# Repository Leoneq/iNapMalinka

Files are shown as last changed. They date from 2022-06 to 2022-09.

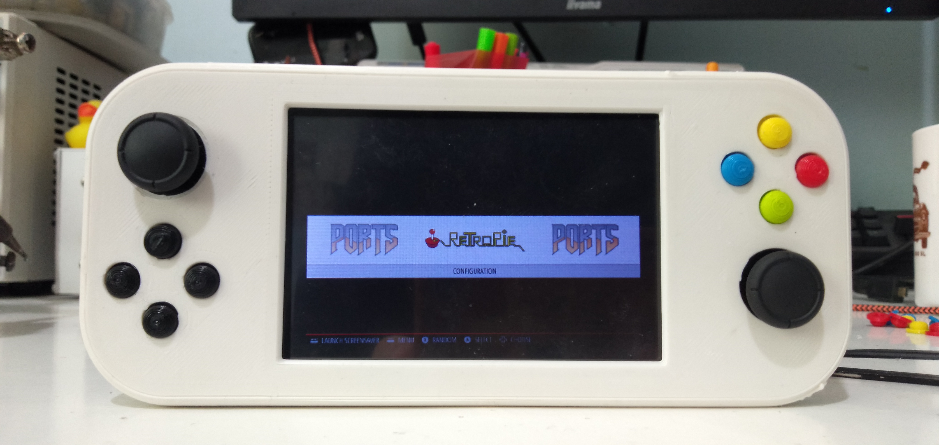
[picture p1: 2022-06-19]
docs/pics/handheld.jpg

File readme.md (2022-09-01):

<div align="center">
  <!--<img src="https://user-images.githubusercontent.com/36605644/186421197-38b28a8d-5e08-4fb6-909e-2cd580bfd80f.png" width=50%>
  <img src="https://user-images.githubusercontent.com/36605644/186671484-4449b216-6cbb-4c44-be21-de949b300e96.jpg" width=50%>-->
  
  <h1>✨ Welcome to the iNap Malinka main page! ✨</h1>
</div>

**iNap Malinka** was mostly made as a decent Raspberry Pi based NRF24L01 transmitter. But as it turns out you can play some games on it as well! It's a small DIY handheld that runs RetroPie so any retro game, including ports, can be played on Malinka. But as it's mostly a device for tinkering on-the-go, there's an additional USB for any kind of peripheral, an HDMI port, and a decent audio section too.
Not only that, it's just as big as your phone, with only 12mm thickness. Two joysticks, 3.5" capacitive touch screen, powered by Raspberry Pi Zero 2W.  
But, if you're interested just about gaming, you can totally ignore the radio section and use it as a small, DIY handheld!
Formally it's a mobile Human-Machine Interface (HMI), as besides the NRF24L01 you can use WiFi and Bluetooth to control your devices!!

## ❤ Why Malinka?
* small and compact size
* big, colorful LCD with touch!
* two joysticks allowing more modern games to be played
* NRF24L01 radio makes it a perfect remote!!
* only 3 external ICs, **without** any aux microcontroller
* stereo sound output and a headphone jack
* custom overlay
* with a keyboard, it can act as a little PC
* uses parts from Nintendo Switch

## 💔 Why NOT?
* if you're a fan of Steam Deck, this device is probably too small for you
* lack of joystick pushbuttons as well as analog triggers
* many tools are needed for assembly
* intermediate soldering skills are needed
* uses parts from Nintendo Switch

## 🚀 Features
* 3.5" 480x320 ILI9488 screen with FT6236 capacitive touch controller
* Raspberry Pi Zero 2W
* 1500mAh lipo battery
* 160x70x12mm (with case)
* two joysticks with 10 bit ADC MCP3008
* PAM8403 amplifier, stereo
* NRF24L01 PA+LNA radio with external antenna (optional)
* Micro-USB for peripherals and USB-C for charging

## 🔨 Kits
There aren't any kits at the moment, you'll need to buy everything by yourself - please visit the [wiki](https://github.com/Leoneq/iNapMalinka/wiki)!
If you want to sell kits of Malinka, please contact me.

## 🎨 Watch it go!
<!--
<div width="60%"> <a href="https://youtu.be/3jcoJ1oJTtw" title="sans gaming"><img src="https://res.cloudinary.com/marcomontalbano/image/upload/v1662052910/video_to_markdown/images/youtube--3jcoJ1oJTtw-c05b58ac6eb4c4700831b2b3070cd403.jpg" alt="sans gaming" /></a></div>
-->
* sans gaming: https://youtu.be/3jcoJ1oJTtw

## ✏ To-do:
* range test video
* doom gaming video
* radio demo video
* improve software a little bit
* and finish wiki ofc

## 😎 Find the project elsewhere
* [OSHWLab](https://oshwlab.com/leoneq/konsola) for schematics and PCB source
* [GitHub](https://github.com/Leoneq/iNapMalinka) for wiki and hardware source
* [Hackaday](https://hackaday.io/project/186233-inap-malinka) for fun
* [Hacksterio](https://www.hackster.io/leonek/inap-malinka-1ea718) for even more fun!!
* [Instructables](https://www.instructables.com/INap-Malinka-Your-NRF24L01-Transmitter-That-Can-Pl/) for the assembly guide
* [Printables](https://www.printables.com/pl/model/265907) for 3D models
* [Thingiverse](https://www.thingiverse.com/thing:5426649) for 3D models but ew

If the project becomes quite popular, I may create a discord server or subreddit dedicated to Malinka!

## 🤝 License
Licensed under CC BY-NC-SA 4.0 - that means you can share, contribute, modify, and remix the source as much as you want!
Please remember to mention the original author and don't change the license. If you want to use it commercially, contact me. 
(there's no guarantee that everything works here, but it should)
Remember that anything you do is at your own risk - the author **is not** responsible for anything you do! Good luck!!  



Because of licensing issues, the code has been moved to [iNapMalinka-code](https://github.com/Leoneq/iNapMalinka-code)!  

## 💖 Sponsor
If you liked this project consider buying me a cup of milk:



I also want to thank [Leo the Leon](https://github.com/leo-the-leon) and [TheTrueShadowFox](https://github.com/TheTrueShadowFox) for the help with this project!!

made with ❤ and 🥛 by  
[@leonek112](https://twitter.com/leoneq112)

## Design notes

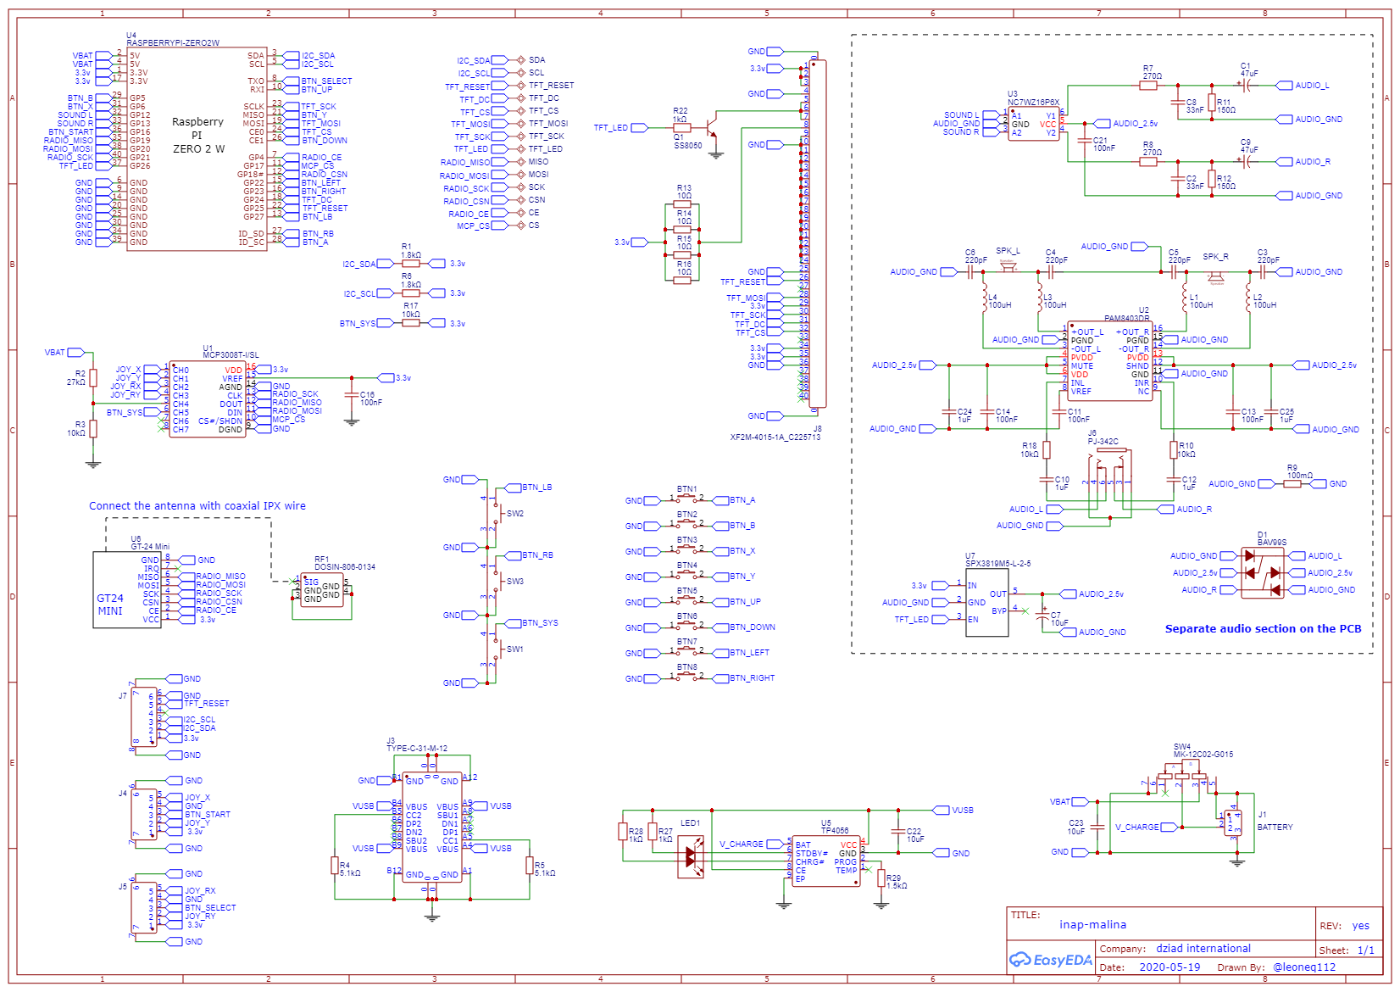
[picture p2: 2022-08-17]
pcb/Schematic_iNap Malinka_2022-08-17.png

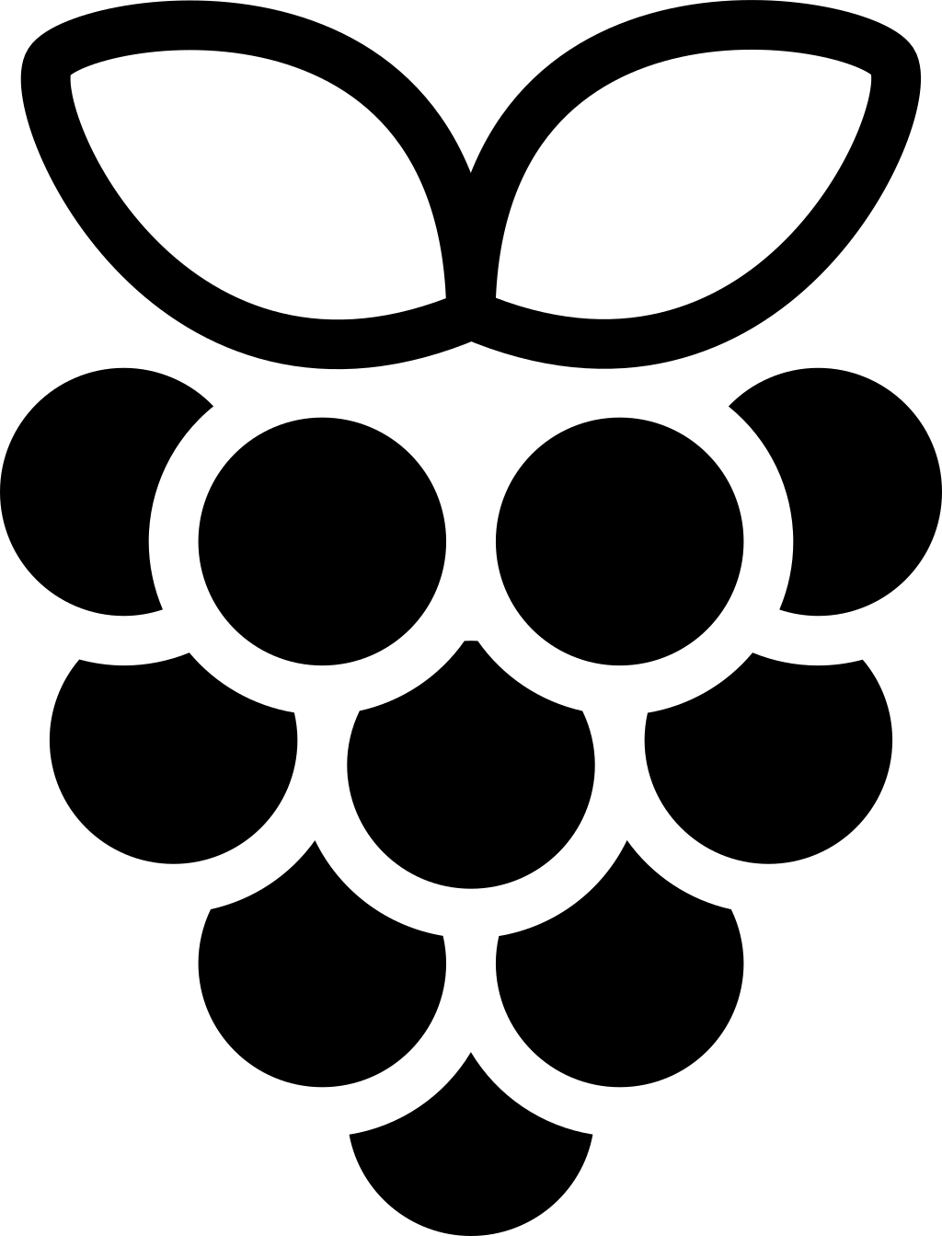
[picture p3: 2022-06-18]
docs/pics/malina.png

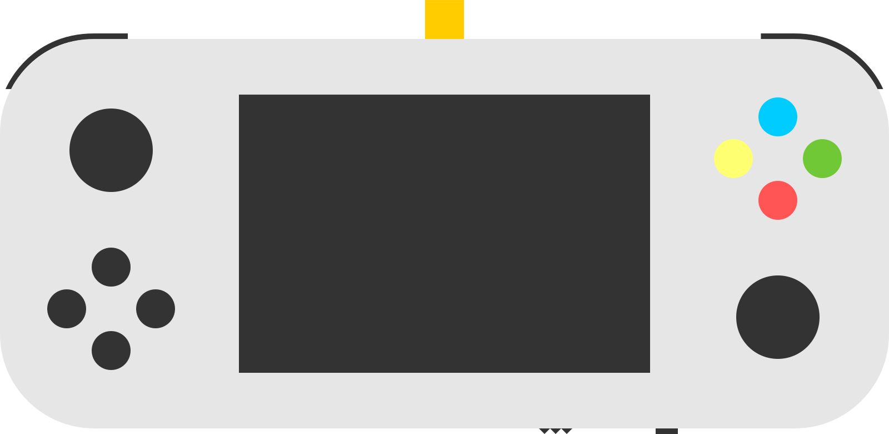
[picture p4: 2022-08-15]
docs/pics/drawing.png

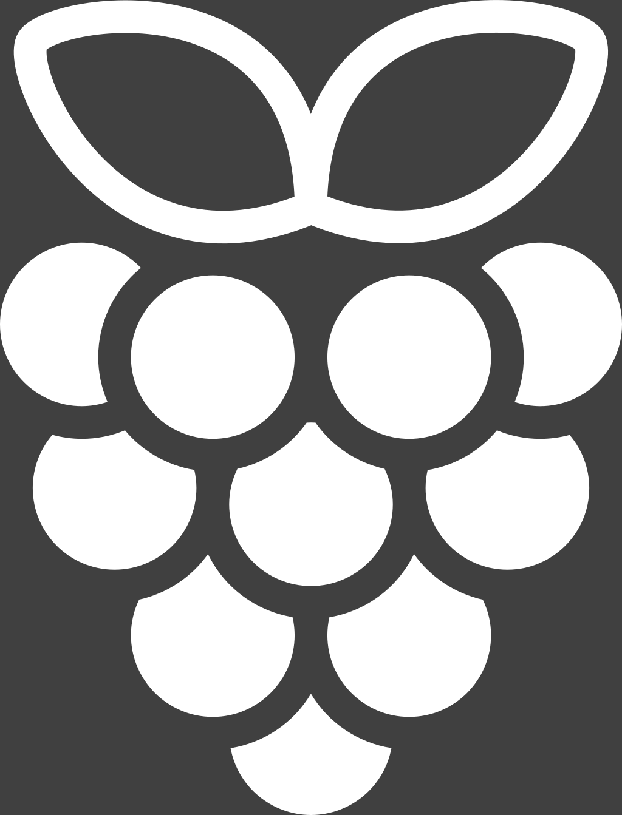
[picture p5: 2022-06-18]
docs/pics/malina_white.png

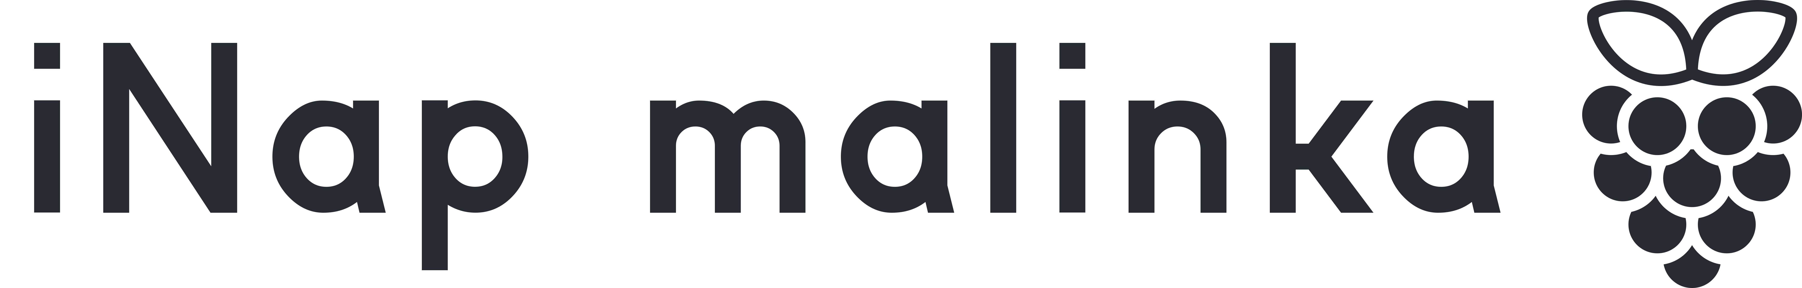
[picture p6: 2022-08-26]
docs/pics/full_malina.png

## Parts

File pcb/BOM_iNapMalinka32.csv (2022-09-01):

ID | Name | Designator | Footprint | Quantity | Manufacturer Part | Manufacturer | Supplier | Supplier Part | Price | Link
1 | K2-3.6×6.1_SMD | BTN1,BTN2,BTN3,BTN4,BTN5,BTN6,BTN7,BTN8 | 4MM BUTTON FIXED | 8 |  |  |  |  |  | none
2 | 47uF | C1,C9 | CAP-TH_BD4.0-P1.50-D0.8-FD | 2 | 47uF 10V 4*5 | ValuePro | LCSC | C43312 | 0.012
3 | 33nF | C2,C8 | C0603 | 2 | CL10B333KB8NFNC | Samsung Electro-Mechanics | LCSC | C307488 | 0.012
4 | 220pF | C3,C4,C5,C6 | C0603 | 4 | CL10B221KB8NNNC | SAMSUNG | LCSC | C1603 | 0.005
5 | 10uF | C7 | CAP-TH_BD4.0-P1.50-D0.8-FD | 1 | 10uF 16V 3*5 | ValuePro | LCSC | C43798 | 0.019
6 | 100nF | C11,C13,C14,C16,C21 | C0603 | 5 | CL10B104KA8NNNC | SAMSUNG | LCSC | C1590 | 0.003
7 | 10uF | C22,C23 | C0805 | 2 | CL21A106KPFNNNE | SAMSUNG | LCSC | C17024 | 0.005
8 | 1uF | C24,C25 | C0603 | 4 | CL10A105KO8NNNC | SAMSUNG | LCSC | C1592 | 0.004
9 | TESTPAD43/80 | CE,CS,CSN,MISO,MOSI,SCK,SCL,SDA,TFT_CS,TFT_DC,TFT_LED,TFT_MOSI,TFT_RESET,TFT_SCK | TESTPAD43/80 | 14 |  |  |  |  |  | none
10 | BAV99S | D1 | SOT-363_L2.1-W1.3-P0.65-LS2.3-BL | 1 | BAV99S | CJ | LCSC | C68987 | 0.047
11 | BATTERY | J1 | CONN-SMD_532610271 | 1 | 532610271 | MOLEX | LCSC | C189700 | 0.107
12 | XF2M-4015-1A_C225713 | J2 | FPC-SMD_40P-P0.50_L4.9-W23.5 | 1 | XF2M-4015-1A | Omron Electronics | LCSC | C225713 | 0.556
13 | TYPE-C-31-M-12 | J3 | USB-C_SMD-TYPE-C-31-M-12 | 1 | TYPE-C-31-M-12 | Rectangular Connectors - Contacts | LCSC | C165948 | 0.249
14 | F0504-H-05-10G-R | J4,J5 | FFC-SMD_5P-P0.50_XFCN_F0504-H-05-10G-R | 2 | F0504-H-05-10G-R | XFCN(台湾兴飞) | LCSC | C2889992 | 0.142
15 | PJ-342C | J6 | AUDIO-SMD_PJ-342C | 1 | PJ-342C | G-Switch(品赞) | LCSC | C2837091 | 0.153
16 | F0504-H-06-10G-R | J7 | FFC-SMD_6P-P0.50_F0504-H-06-10G-R | 1 | F0504-H-06-10G-R | XFCN | LCSC | C510962 | 0.184
17 | 100uH | L1,L2,L3,L4 | L0805 | 4 | MLF2012C101KT000 | TDK | LCSC | C68035 | 0.044
18 | 19-223/R6GHC-A01/2T(YY) | LED1 | LED-ARRAY-SMD_4P-L1.6-W1.5-TR | 1 | 19-223/R6GHC-A01/2T(YY) | Everlight Elec | LCSC | C182213 | 0.086
19 | SS8050 | Q1 | SOT-23-3_L2.9-W1.3-P1.90-LS2.4-BR | 1 | SS8050 | CJ | LCSC | C2150 | 0.016
20 | 1.8kΩ | R1,R6 | R0603 | 2 | ERJ3EKF1801V | PANASONIC | LCSC | C278609 | 0.01
21 | 27kΩ | R2 | R0603 | 1 | RS-03K2702FT | Guangdong Fenghua Advanced Tech | LCSC | C304727 | 0.001
22 | 10kΩ | R3,R17 | R0603 | 4 | 0603WAF1002T5E | UniOhm | LCSC | C25804 | 0.001
23 | 5.1kΩ | R4,R5 | R0603 | 2 | 0603WAF5101T5E | UniOhm | LCSC | C23186 | 0.001
24 | 270Ω | R7,R8 | R0603 | 2 | ERJ3GEYJ271V | PANASONIC | LCSC | C403465 | 0.007
25 | 100mΩ | R9 | R1206 | 1 | 1206W4F100LT5E | UniOhm | LCSC | C25334 | 0.009
26 | 150Ω | R11,R12 | R0603 | 2 | ERJ3RBD1500V | PANASONIC | LCSC | C336847 | 0.021
27 | 10Ω | R13,R14,R15,R16 | R0603 | 4 | 0603WAF100JT5E | UniOhm | LCSC | C22859 | 0.001
28 | 1kΩ | R22,R27,R28 | R0603 | 3 | ERJP03J102V | PANASONIC | LCSC | C427272 | 0.051
29 | 1.5kΩ | R29 | R0603 | 1 | ERJ-3EKF1501V | PANASONIC | LCSC | C193392 | 0.009
30 | DOSIN-806-0134 | RF1 | SMA-SMD_DOSIN-806-0134 | 1 | DOSIN-806-0134 | dosinconn(德索五金) | LCSC | C709670 | 0.98
31 | -SPEAKER | SPK_L,SPK_R | FILTER-SMD_1206-2P-L3.2-W1.6-L | 2 | GSPK1003PN-8R0.2W-L100 | INGHAi | LCSC | C530534 | 0.613
32 | 1TS003B-1400-3500A | SW1,SW2,SW3 | KEY-SMD_1TS003B | 3 | 1TS003B-1400-3500A | HYP | LCSC | C319392 | 0.04
33 | MK-12C02-G015 | SW4 | SW-SMD_G-SWITCH_MK-12C02-G015 | 1 | MK-12C02-G015 | G-Switch(品赞) | LCSC | C2911519 | 0.114
34 | MCP3008T-I/SL | U1 | SOIC-16_L9.9-W3.9-P1.27-LS6.0-BL | 1 | MCP3008T-I/SL | MICROCHIP(美国微芯) | LCSC | C2651321 | 5.146
35 | PAM8403DR | U2 | SOIC-16_L9.9-W3.9-P1.27-LS6.0-BL | 1 | PAM8403DR | DIODES | LCSC | C17337 | 0.425 | Available on green audio amplifier boards.
36 | NC7WZ16P6X | U3 | SC-70-6_L2.2-W1.3-P0.65-LS2.1-BR | 1 | NC7WZ16P6X | ON Semicon | LCSC | C114148 | 0.772
37 | RASPBERRYPI-ZERO2W | U4 | RPI2W_USB | 1 |  |  |  |  | 15
38 | TP4056 | U5 | SOP-8_L4.9-W3.9-P1.27-LS6.0-TL-EP-1 | 1 | TP4056X | TOPPOWER(南京拓微) | LCSC | C2763448 | 0.205
39 | GT-24 Mini | U6 | GT24 MINI | 1 |  |  |  |  | 1.83
40 | SPX3819M5-L-2-5 | U7 | SOT-23-5_L3.0-W1.7-P0.95-LS2.8-TL | 1 | SPX3819M5-L-2-5 | EXAR | LCSC | C21454 | 0.77
41 | M2x3x3 brass insert |  | M2x3x3 | 6 |  |  |  |  |  | https://aliexpress.com/item/1005002529889373.html
42 | M2x10 |  | M2x10 | 6 | KM2X10 | Shuntian | LCSC | C357345 | 0.0018
43 | M1.4x4 |  | M1.4x10 | 4 | KA1.4X4 | Shuntian | LCSC | C357505 | 0.0009
44 | Nintendo Switch Lite buttons pads |  | left and right | 1 |  | Nintendo |  |  | 1.53 | https://aliexpress.com/item/1005003071063706.html
45 | Nintendo Switch Joystick |  |  | 2 |  | Nintendo |  |  | 2.27 | https://aliexpress.com/item/4001209760173.html
46 | 3.5inch IlI9488 screen with CTP |  |  | 1 | LHC03540 | LiangHaoCai |  |  | 14.85 | https://aliexpress.com/item/4001248271603.html
47 | 1500mAh 3.7v LiPo 40x50x5mm |  |  |  | 504050 | Liter Energy |  |  | 5.18 | https://aliexpress.com/item/4000036287535.html

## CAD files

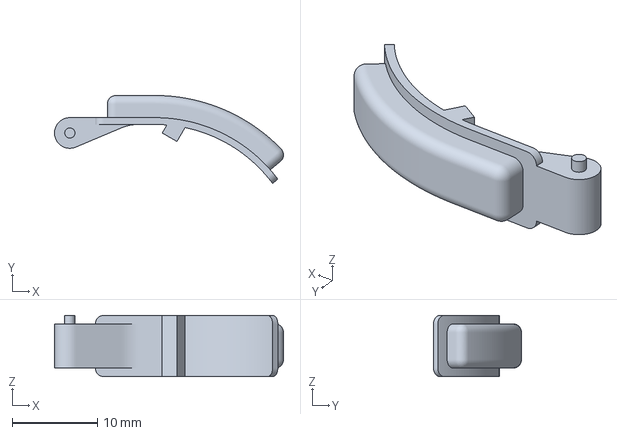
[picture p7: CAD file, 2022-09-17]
print/trigger_right.3mf
26.9 x 10.3 x 7.20 mm

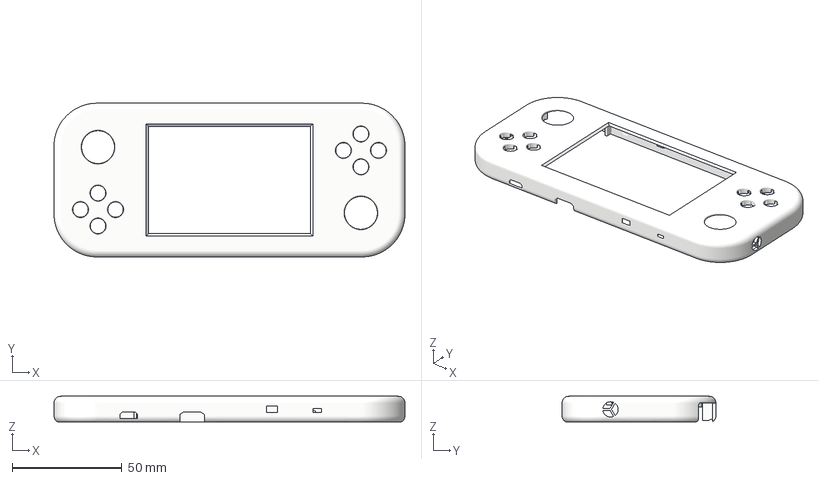
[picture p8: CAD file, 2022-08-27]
print/shell_no_sma.3mf
160.2 x 70.2 x 11.7 mm

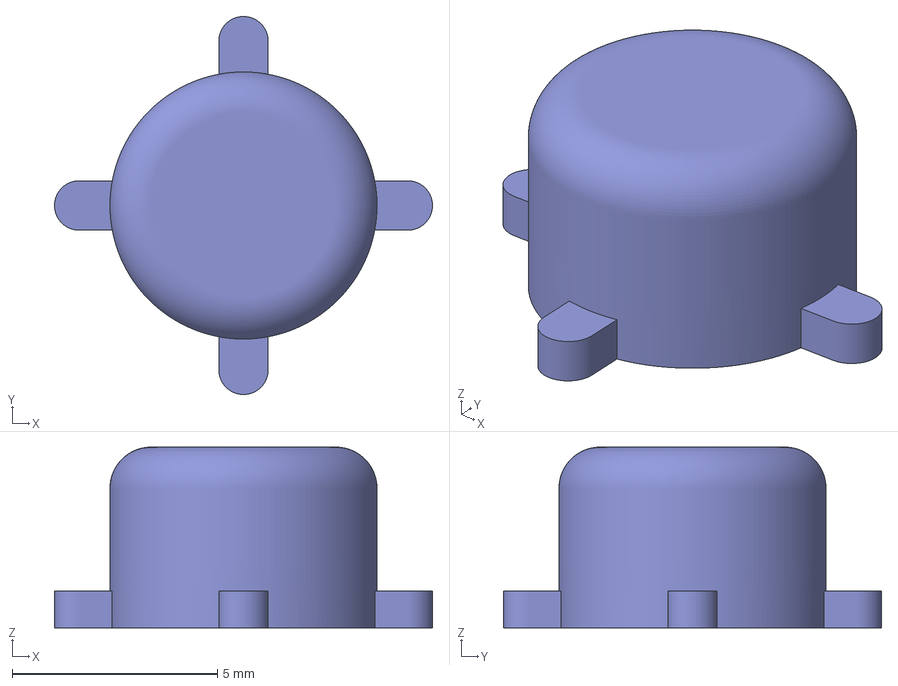
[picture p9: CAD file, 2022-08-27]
print/btn.3mf
9.20 x 9.20 x 4.40 mm

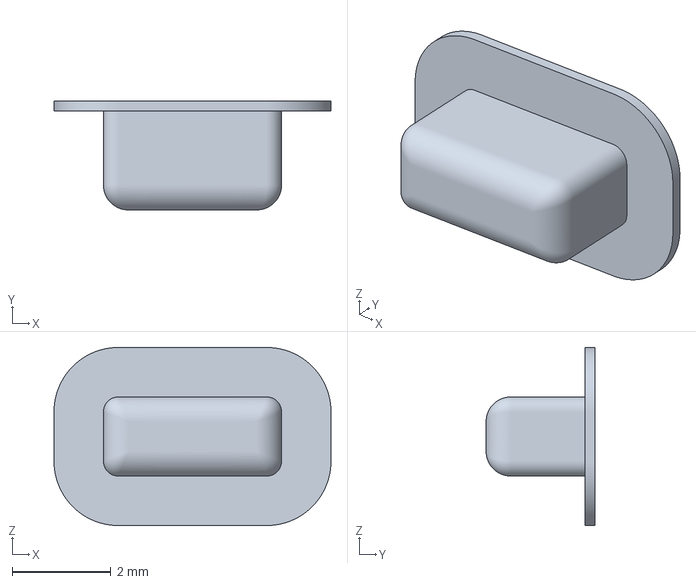
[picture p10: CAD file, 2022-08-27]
print/sysbtn.3mf
5.60 x 2.20 x 3.60 mm

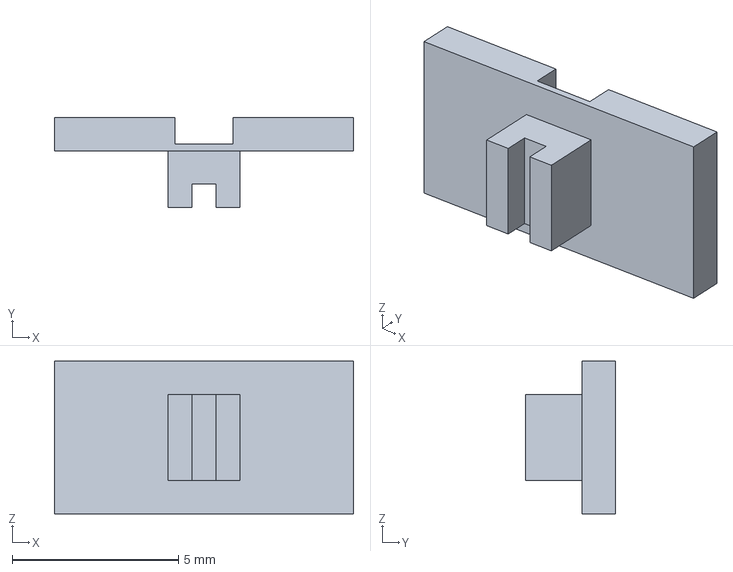
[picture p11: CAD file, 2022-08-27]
print/switch.3mf
9.00 x 2.70 x 4.60 mm

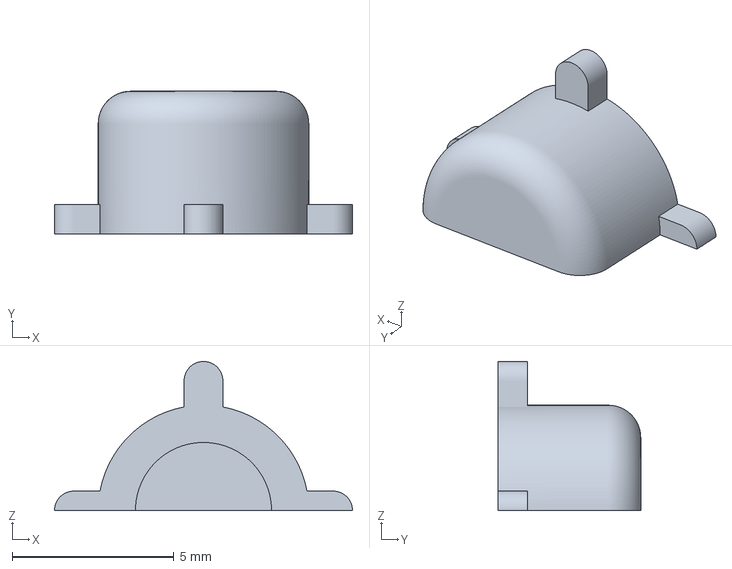
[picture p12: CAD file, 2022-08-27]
print/btn_half.3mf
9.20 x 4.40 x 4.60 mm

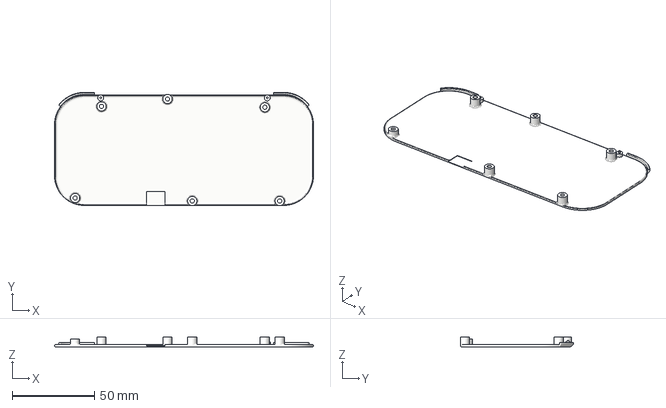
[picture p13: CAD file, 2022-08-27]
print/cover.3mf
157.0 x 68.6 x 6.20 mm

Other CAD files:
print/trigger_left.3mf
print/shell.3mf
print/malinka.f3z

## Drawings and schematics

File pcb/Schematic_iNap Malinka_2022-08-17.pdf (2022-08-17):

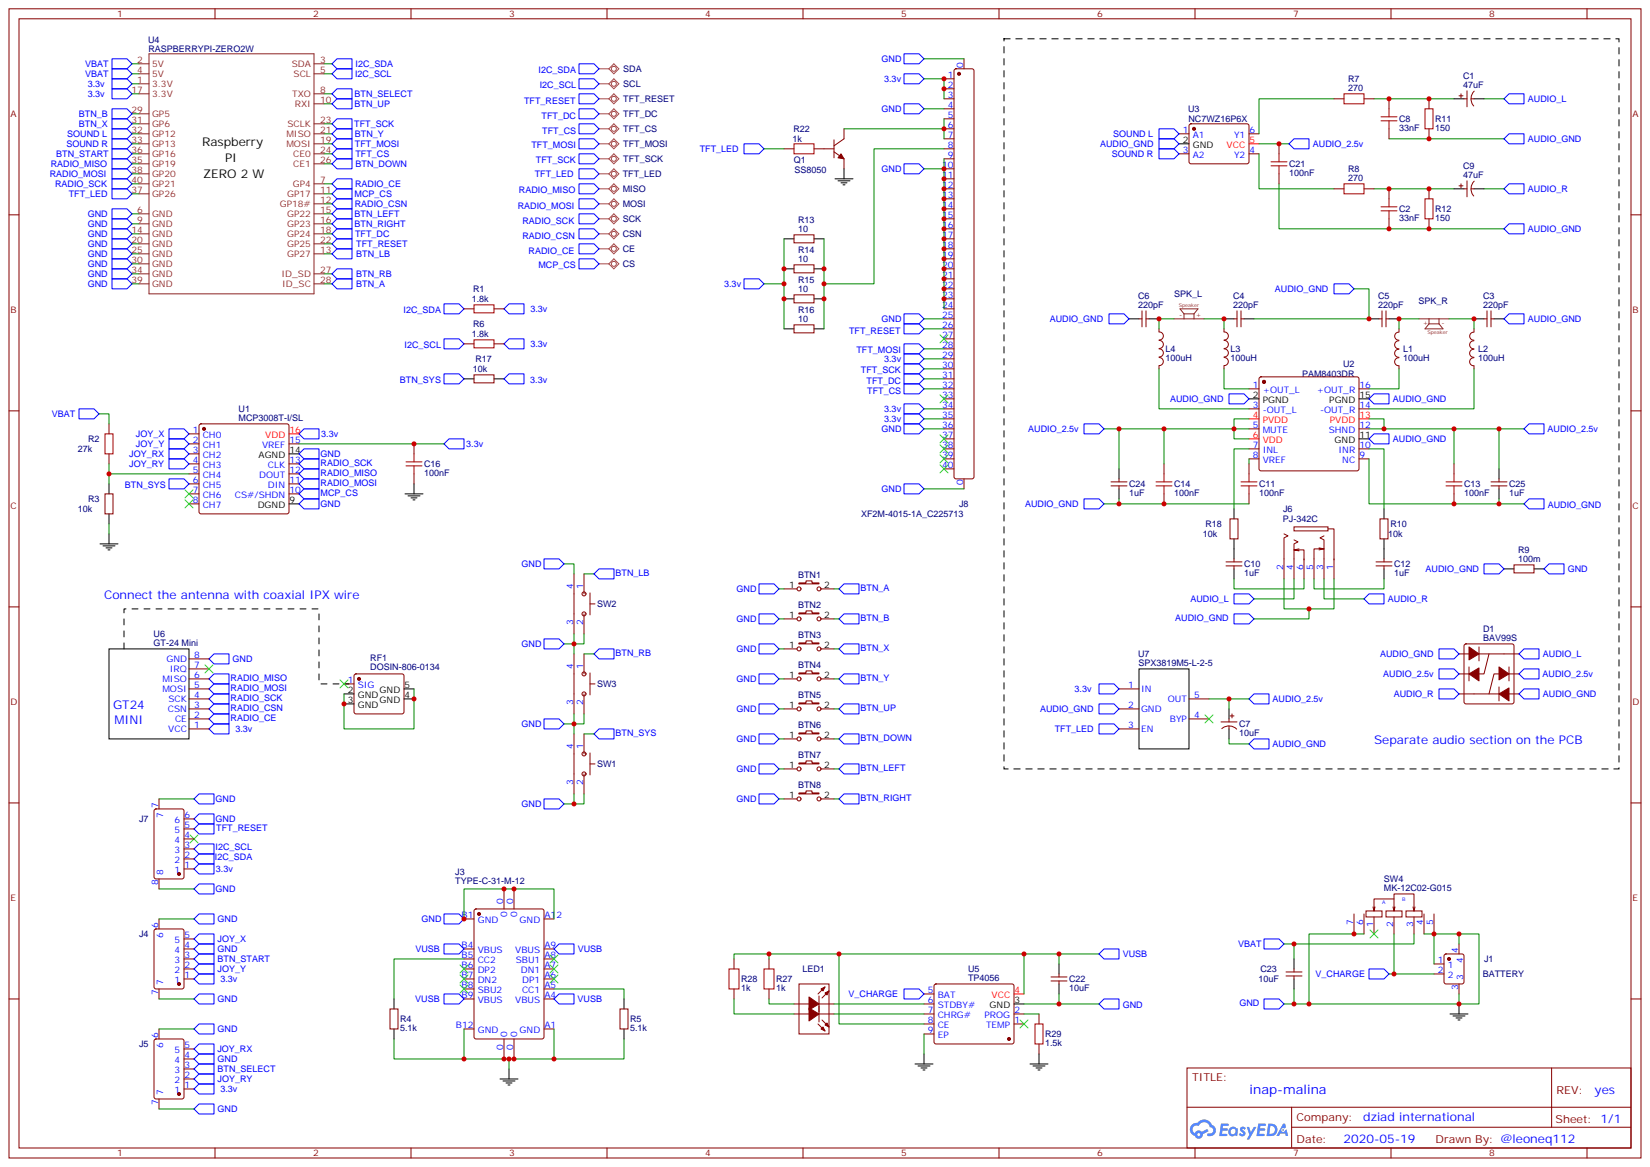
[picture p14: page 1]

MCP3008T-I/SL
CS#/SHDN 10 DIN 11 DOUT 12 CLK 13 AGND 14 VREF 15 VDD 16

Connect the antenna with coaxial IPX wire

Separate audio section on the PCB

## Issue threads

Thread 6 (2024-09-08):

Cant find the material list!

Pocke01, 2024-09-08:
Like the title says. I can only find some parts under features but I would like to have all the parts. Could you please add a material list. :)

Leoneq, 2024-09-09:
Hi! The part list is included as a BOM file in the 'pcb' folder: [BOM_iNapMalinka32.csv](https://github.com/Leoneq/iNapMalinka/blob/main/pcb/BOM_iNapMalinka32.csv)

Pocke01, 2024-09-09:
Thank you!  How could i miss that one.

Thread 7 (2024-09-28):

question

Pocke01, 2024-09-28:
Hi,

Have a question.  The pcb i got when order from the files in the repo has r10, c12,c18, c10 but the picture of your finished board does not have those.  Is it only to ignore them ? They are on the sides of C11

And the place where you say "DO NOT solder L1-L4, or C3-C6, but instead short them as shown:"
c3-c6 is left as is? no solder at all?

Leoneq, 2024-09-29:
Hi!
Yes, the pictured board is a prototype version, good eye. I was creating instructions along when soldering the prototype, and the sound turned out to be of poor quality till those passives were added.
You need to solder them as the schematic shows, I will update the wiki soon.

As for L1-L4 and C3-C6 I agree it's a wrong sentence, I'll change that too - but as shown, short L1-L4 unless you still get a poor quality sound, and C3-C6 should be left free (just as the picture shows)

Pocke01, 2024-09-29:
What passives goes on  r10, c12,c18, c10 ?

And is it possible to run without battery only usb-c power?  Cause we havent recieved the battery yet. But my son has finished almost all the soldering.

Leoneq, 2024-09-29:
As seen here: https://github.com/Leoneq/iNapMalinka/blob/main/pcb/Schematic_iNap%20Malinka_2022-08-17.pdf
In the audio section you can see what values those are. To run without battery you will need to short the `VBAT` with `VUSB`; follow the schematic to see what would be the best place to put the jumper on. Everything should work fine except the overlay, which may show something like "200%" battery charge.

Pocke01, 2024-09-29:
Thanks for the help!

Closed 2024-09-29.

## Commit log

2022-06-18 added some cool files
    [config.txt]
2022-06-19 added some essential files
    [BOM_iNap Malinka_2022-06-16.csv, button.3mf, buttons_connected.3mf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]
2022-07-06 Updated 3D models
    [btn_side.3mf, button.3mf, buttons_connected.3mf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]
2022-07-06 More changes
    [BOM_iNap Malinka_2022-06-16.csv, BOM_iNapMalinka32.csv]
2022-08-19 updated bom
    [BOM_iNapMalinka32.csv, OLD_BOM_iNapMalinka32.csv]
2022-08-27 updated models
    [btn.3mf, btn_half.3mf, cover.3mf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]
2022-08-27 added f3z file
    [malinka.f3z, shell_no_sma.3mf]
2022-09-01 correct invalide quote (#5)
    made the file directly editable on github
    [BOM_iNapMalinka32.csv]
2022-09-17 simplified triggers geometry
    [trigger_left.3mf, trigger_right.3mf]
